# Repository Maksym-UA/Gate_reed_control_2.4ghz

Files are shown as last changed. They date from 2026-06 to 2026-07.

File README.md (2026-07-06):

# Gate Reed Control 2.4GHz & Telegram Bot

## Overview

Dual-board ESP32 project for gate door-state telemetry over ESP-NOW.

- Xiao ESP32-C3 acts as the transmitter
- ESP32-S3 acts as the receiver with Telegram bot push notifications
- Framework: ESP-IDF via PlatformIO
- Transport: ESP-NOW (2.4 GHz) + HTTPS (Telegram Bot API)

Each firmware keeps `src/main.cpp` minimal and places runtime logic in `src/application.cpp`.

## Demo

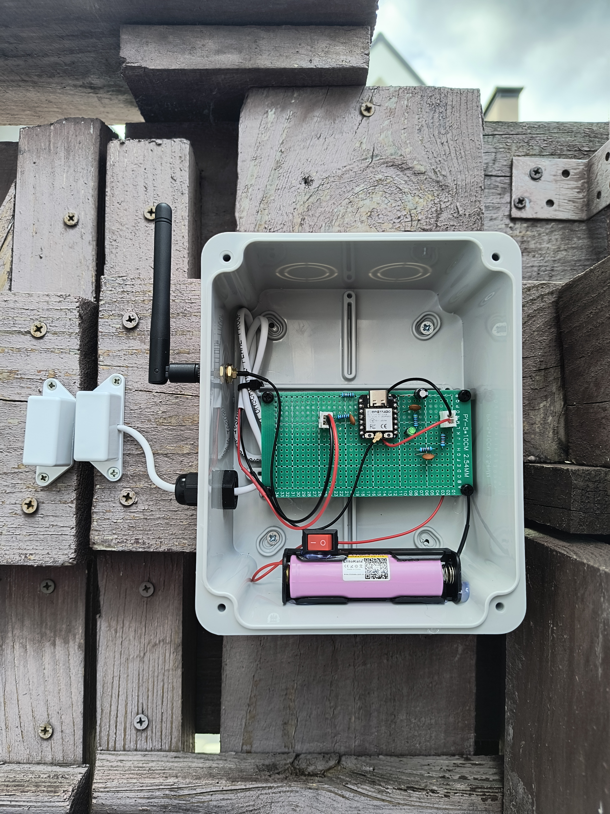
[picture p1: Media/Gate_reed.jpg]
Watch the demo (https://github.com/Maksym-UA/Gate_reed_control_2.4ghz/releases/download/v1.0.1/Reed_operation.mp4)


[Video walkthrough](https://github.com/Maksym-UA/Gate_reed_control_2.4ghz/releases/download/v1.0.1/Reed_operation.mp4)

_Fallback (repo file): [Media/Reed_operation.mp4](Media/Reed_operation.mp4)_

## Hardware

| Board | Role | Key GPIO |
|---|---|---|
| ESP32-C3 (Seeed XIAO ESP32C3) | Reed sensor reader + ESP-NOW TX + deep sleep | Reed: GPIO4, LED: GPIO20 |
| ESP32-S3 (ESP32-S3-DevKitC-1) | ESP-NOW RX + WiFi STA + Telegram bot | No sensor GPIO; WiFi used for Telegram HTTPS |

### Wiring Notes

- Use an external 100k pull-up resistor on ESP32-C3 GPIO4 for the reed input line for more efficient power management.
- Add an MTS-101 switch on the battery path so battery power can be disconnected while the ESP32-C3 is powered from USB.

## Communication Model

ESP32-C3 publishes gate state messages:

- `DOOR:OPEN`
- `DOOR:CLOSED`
- `BATT:X.XXV` (periodic battery voltage, e.g. `BATT:3.92V`)

ESP32-S3 listens on ESP-NOW, updates remote door state, and marks state as stale if no packet arrives for a timeout window.

## Build, Upload, Monitor

ESP32-C3:

```bash
cd ESP32-C3
pio run
pio run -t upload
pio device monitor -b 115200
```

ESP32-S3:

```bash
cd ESP32-S3
pio run
pio run -t upload
pio device monitor -b 115200
```

## Telegram Bot Setup

The ESP32-S3 connects to a Telegram bot to deliver door-state push notifications and respond to admin commands.

### Credentials

Credentials are stored in `ESP32-S3/lib/esp_now/telegram/secrets.h`, which is gitignored.

1. Copy the template:
   ```bash
   cp ESP32-S3/lib/esp_now/telegram/secrets.h.template \
      ESP32-S3/lib/esp_now/telegram/secrets.h
   ```
2. Fill in the values:
   ```c
   #define WIFI_SSID      "your_wifi_ssid"
   #define WIFI_PASSWORD  "your_wifi_password"
   #define TG_BOT_TOKEN   "123456:ABC-..."
   #define TG_CHAT_ID     "123456789"   // chat to receive notifications
   #define TG_ADMIN_ID    "123456789"   // user ID allowed to run admin commands
   ```
3. Create a bot with [@BotFather](https://t.me/BotFather) and copy the token.
4. Retrieve your chat/user ID via [@userinfobot](https://t.me/userinfobot) or `getUpdates`.

### Notifications

| Event | Telegram message |
|---|---|
| Door opened | 🚪 Двері ВІДЧИНЕНІ |
| Door closed | ✅ Двері ЗАЧИНЕНІ |
| Door still open (every 5 min) | ⚠️ Двері все ще ВІДЧИНЕНІ: Xхв Yс |

### Admin Commands

| Command / Button | Response |
|---|---|
| `/voltage` text message | Battery voltage or "no data yet" |
| `Check Voltage` inline button | Same as `/voltage` |

Only `TG_ADMIN_ID` receives voltage data; all others get an unauthorized reply.

### Transport

The bot uses **long-polling** (`getUpdates` with `timeout=25`). No webhook or public IP is required. All HTTPS calls run inside a dedicated `tg_task` FreeRTOS task so the main door-state loop never blocks on network I/O.

## Runtime Flow

ESP32-C3:

1. Initializes ESP-NOW, reed input, LED, and ADC voltage divider.
2. Reads current door state and transmits initial state (`BOOT` TX kind on first cold boot).
3. Blinks LED 3 times for OPEN, 1 time for CLOSED on state change.
4. On timer wake with unchanged state, transmits `KEEPALIVE` once the periodic keep-alive threshold is reached.
5. On timer wake, spawns a one-shot voltage task that reads the battery ADC and broadcasts `BATT:X.XXV` when the battery TX interval threshold is reached.
6. Waits in boot grace window (15 s) on cold boot to allow monitoring/flashing.
7. On wake from GPIO/timer, stays active briefly (3.5 s) to catch quick follow-up transitions.
8. Enters deep sleep; wakes on reed pin level change (GPIO wakeup) with a timer fallback wake.

ESP32-S3:

1. Initializes ESP-NOW, connects to WiFi, and starts the Telegram bot client.
2. Receives `DOOR:OPEN` / `DOOR:CLOSED` / `BATT:X.XXV` packets via ESP-NOW.
3. Tracks known/unknown remote door state; marks it stale after a timeout without packets.
4. Enqueues Telegram notifications: door opened, door closed, and a repeat reminder every 5 minutes while the door remains open.
5. Runs a dedicated `tg_task` (FreeRTOS) for all HTTPS operations — the main loop never blocks on network I/O.
6. Long-polls Telegram (25 s server timeout) for admin commands: `/voltage` text message and `CHECK_VOLTAGE` inline button.
7. Logs a periodic heartbeat with the current door state.

## System Architecture

This project follows a layered architecture across two boards:

- **ESP32-C3 transmitter** — reads the reed sensor, measures battery voltage, drives the status LED, and sends ESP-NOW packets.
- **ESP32-S3 receiver** — receives ESP-NOW packets, tracks remote state, and reports status through logs.

### GPIO Map

| Board | GPIO / Resource | Function |
|---|---|---|
| ESP32-C3 (Seeed XIAO ESP32C3) | GPIO4 | Reed sensor input |
| ESP32-C3 (Seeed XIAO ESP32C3) | GPIO2 | Battery voltage ADC input |
| ESP32-C3 (Seeed XIAO ESP32C3) | GPIO20 | Green LED output |
| ESP32-C3 (Seeed XIAO ESP32C3) | ESP-NOW / Wi-Fi | Wireless transmission |
| ESP32-C3 (Seeed XIAO ESP32C3) | Deep sleep wakeup | Wake by GPIO or timer |
| ESP32-S3 (ESP32-S3-DevKitC-1) | ESP-NOW / Wi-Fi | Wireless reception |
| ESP32-S3 (ESP32-S3-DevKitC-1) | UART | Debug and monitoring output |

### Peripheral List

ESP32-C3 transmitter:
- Reed switch sensor
- External 100k pull-up resistor on GPIO4
- RC input filter: 100Ω + 100nF
- Battery voltage divider on GPIO2: 220k / 220k
- ADC filter capacitor: 100nF
- Green LED with 470Ω resistor
- 18650 Li-ion battery
- Power switch
- ESP-NOW wireless interface

ESP32-S3 receiver:
- ESP-NOW wireless interface (2.4 GHz)
- WiFi STA (WPA2, used for Telegram HTTPS)
- UART logging interface

### Layer Model

#### Peripheral Layer
Handles low-level hardware setup.

ESP32-C3:
- Reed GPIO initialization
- LED GPIO initialization
- ADC initialization for battery sensing
- ESP-NOW initialization
- Deep sleep and wakeup source setup

ESP32-S3:
- ESP-NOW initialization
- UART/logger initialization

#### Logic Layer
Implements the application behavior.

ESP32-C3:
- Reed state reading
- Debounce/filtering
- Door state evaluation
- Keepalive scheduling
- Battery reporting scheduling
- Wake reason handling
- Sleep decision logic

ESP32-S3:
- Packet parsing
- Door state tracking
- Battery status update
- Timeout and stale-state detection

#### Transport / Output Layer
Handles communication and visible output.

ESP32-C3:
- ESP-NOW transmission of:
  - `DOOR:OPEN`
  - `DOOR:CLOSED`
  - `BATT:X.XXV`
- LED blink indication

ESP32-S3:
- ESP-NOW packet reception
- WiFi STA connection (WPA2)
- Telegram push notifications via HTTPS (`sendMessage`)
- Telegram long-poll command handler (`/voltage`, `CHECK_VOLTAGE` inline button)
- UART log output

#### Reliability Layer
Improves robustness and fault tolerance.

ESP32-C3:
- ADC averaging
- ADC settle delay before sampling
- ESP-NOW retry handling
- Wait for TX completion before sleep
- Deep sleep power saving
- GPIO/timer wakeup recovery

ESP32-S3:
- Timeout detection
- Stale-state handling
- Recovery after missed packets

### High-Level Architecture Diagram

```mermaid
flowchart LR
    subgraph TX["ESP32-C3 Transmitter"]
        RS["Reed Sensor"]
        BAT["18650 Battery"]
        SW["Power Switch"]
        LED["Green LED"]

        subgraph P1["Peripheral Layer"]
            GPIO["GPIO4 Reed Input"]
            ADC["GPIO2 ADC Battery Input"]
            LEDGPIO["GPIO20 LED Output"]
            ESPNOW1["ESP-NOW Init"]
            SLEEP1["Deep Sleep / Wakeup Init"]
        end

        subgraph L1["Logic Layer"]
            REEDLOGIC["Reed Read + Debounce"]
            FSM1["Door State FSM"]
            BATTLOGIC["Battery Read Scheduler"]
            KEEP["Keepalive Logic"]
        end

        subgraph O1["Transport / Output Layer"]
            TXMSG["ESP-NOW TX\nDOOR:OPEN / DOOR:CLOSED / BATT:X.XXV"]
            LEDPAT["LED Blink Patterns"]
        end

        subgraph R1["Reliability Layer"]
            AVG["ADC Averaging"]
            TXRETRY["TX Retry / Wait Complete"]
            WAKE["GPIO / Timer Wake Logic"]
        end

        RS --> GPIO
        BAT --> SW --> ADC
        BAT --> SW --> SLEEP1
        GPIO --> REEDLOGIC --> FSM1
        ADC --> BATTLOGIC
        FSM1 --> TXMSG
        KEEP --> TXMSG
        BATTLOGIC --> TXMSG
        FSM1 --> LEDPAT
        LEDPAT --> LEDGPIO --> LED

        ESPNOW1 --> TXMSG
        SLEEP1 --> WAKE
        AVG --> BATTLOGIC
        TXRETRY --> TXMSG
        WAKE --> FSM1
    end

    LINK["2.4 GHz ESP-NOW Link"]

    subgraph RX["ESP32-S3 Receiver"]
        subgraph P2["Peripheral Layer"]
            ESPNOW2["ESP-NOW Init"]
            WIFI["WiFi STA Init"]
            UART["UART / Serial Log Init"]
        end

        subgraph L2["Logic Layer"]
            PARSE["Packet Parser"]
            FSM2["Receiver State FSM"]
            STALE["Timeout / Stale Detection"]
            BATT2["Battery Status Update"]
            TG_QUEUE["Telegram Queue"]
            TG_TASK["tg_task\n(FreeRTOS)"]
        end

        subgraph O2["Transport / Output Layer"]
            LOG["UART Logs / Monitoring"]
            TG["Telegram Bot API\n(HTTPS long-poll + POST)"]
        end

        subgraph R2["Reliability Layer"]
            REC["Recovery / Timeout Handling"]
        end

        ESPNOW2 --> PARSE
        WIFI --> TG_TASK
        PARSE --> FSM2
        PARSE --> BATT2
        FSM2 --> TG_QUEUE
        BATT2 --> LOG
        TG_QUEUE --> TG_TASK
        TG_TASK --> TG
        FSM2 --> LOG
        STALE --> FSM2
        REC --> STALE
        UART --> LOG
    end

    TXMSG --> LINK --> ESPNOW2
```

### Transmitter Runtime FSM

```mermaid
stateDiagram-v2
    [*] --> BOOT
    BOOT --> INIT
    INIT --> CHECK_REED

    CHECK_REED --> SEND_EVENT : door changed
    CHECK_REED --> SEND_KEEPALIVE : keepalive due
    CHECK_REED --> READ_BATTERY : battery report due
    CHECK_REED --> PREPARE_SLEEP : no update needed

    SEND_EVENT --> BLINK_LED
    BLINK_LED --> WAIT_TX_DONE
    SEND_KEEPALIVE --> WAIT_TX_DONE
    READ_BATTERY --> SEND_BATTERY
    SEND_BATTERY --> WAIT_TX_DONE

    WAIT_TX_DONE --> PREPARE_SLEEP
    PREPARE_SLEEP --> DEEP_SLEEP
    DEEP_SLEEP --> WAKE

    WAKE --> CHECK_REED
```

### Receiver Runtime FSM

```mermaid
stateDiagram-v2
    [*] --> INIT
    INIT --> LISTENING

    LISTENING --> PARSE_PACKET : packet received
    PARSE_PACKET --> STATE_OPEN : DOOR:OPEN
    PARSE_PACKET --> STATE_CLOSED : DOOR:CLOSED
    PARSE_PACKET --> UPDATE_BATTERY : BATT:X.XXV

    STATE_OPEN --> ENQUEUE_NOTIFY : state changed
    STATE_OPEN --> LISTENING : keepalive (no change)
    STATE_CLOSED --> ENQUEUE_NOTIFY : state changed
    STATE_CLOSED --> LISTENING : keepalive (no change)
    ENQUEUE_NOTIFY --> LISTENING
    UPDATE_BATTERY --> LISTENING

    LISTENING --> ENQUEUE_REMIND : door open ≥ 5 min
    ENQUEUE_REMIND --> LISTENING

    LISTENING --> STATE_STALE : packet timeout
    STATE_STALE --> LISTENING : next valid packet
```

### Queue and Mutex Notes

- A **queue** is used when one task sends commands to another task.
- In this project, the LED control path is a queue-based interaction between application logic and the LED task.
- A **mutex** is needed when multiple tasks access the same shared resource.
- If multiple tasks transmit through the same ESP-NOW path, a mutex may be used to protect the shared transmission resource.

## Project Structure

```text
ESP32-C3/
  include/
    application.h
  lib/
    esp_now/
    led/
    reed/
    voltage/
  src/
    application.cpp
    main.cpp
  CMakeLists.txt
  platformio.ini

ESP32-S3/
  include/
    application.h
  lib/
    esp_now/
      esp_now.cpp
      espnow_service.h
      telegram/
        telegram.cpp
        telegram.h
        secrets.h          ← gitignored; copy from secrets.h.template
        secrets.h.template
  src/
    application.cpp
    main.cpp
  CMakeLists.txt
  platformio.ini

Gate_reed_control_2.4ghz.code-workspace
.gitignore
README.md
src/
```

## Notes

- ESP-NOW is connectionless and best-effort; RF environment affects reliability.
- Deep sleep on ESP32-C3 may make USB serial disappear until the next wake/reset.
- If VS Code shows stale Problems after successful builds, run a clean build and reload the window.
- `ESP32-S3/lib/esp_now/telegram/secrets.h` is gitignored. Copy `secrets.h.template` to `secrets.h` and fill in your credentials before building the S3 firmware.
- KiCAd Xiao ESP32-C3 footprint from https://github.com/VectorSpaceHQ/XIAO_ESP32C3
- Seeed Xiao ESP32-C3 Wiki https://wiki.seeedstudio.com/XIAO_ESP32C3_Getting_Started

## Contact

Feedback: max.savin3@gmail.com

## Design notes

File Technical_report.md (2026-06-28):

# Technical Report

## Abstract

This project implements a simple wireless gate monitoring system using two ESP32 boards and ESP-NOW communication. The ESP32-C3 transmitter reads a reed switch, measures battery voltage, and sends status packets. The ESP32-S3 receiver listens for these packets, updates the remote gate state, and reports the current status through logs.

The system was designed for low-power battery operation. The transmitter uses deep sleep, GPIO wakeup, timer wakeup fallback, and periodic battery reporting. The software is structured into four layers: Peripheral Layer, Logic Layer, Transport / Output Layer, and Reliability Layer. This makes the design easier to understand, test, and maintain.

Testing confirmed correct gate state detection, correct wireless transmission, and correct battery measurement after fixing the physical ADC wiring. The final result is a compact embedded system suitable for simple remote monitoring applications.

## Problem Statement

The goal of this project was to create a battery-powered embedded system that can detect whether a gate or door is open or closed and send this information wirelessly to another ESP32 board. The system also had to report battery voltage and support low-power operation.

The transmitter had to read a reed sensor, detect state changes, send updates through ESP-NOW, and spend most of its time in deep sleep to reduce power consumption. The receiver had to listen for incoming packets, track the last known state, and detect when communication becomes stale.

The solution had to remain simple, practical, and easy to test on real hardware.

## Review of Existing Solutions

A basic way to monitor a gate or door is to connect a reed switch directly to a wired alarm or controller input. This is reliable but requires cabling.

Wireless systems often use Wi-Fi, Bluetooth Low Energy, Zigbee, LoRa, or MQTT-based architectures. These solutions can be powerful, but they often require more infrastructure, more software complexity, or more power.

ESP-NOW is a lightweight wireless protocol supported by ESP32 devices. It does not require a router or access point and is well suited for simple ESP32-to-ESP32 communication. For this reason, it was selected as the communication method for this project.

Battery voltage measurement is commonly implemented with a resistor divider connected to an ADC pin. This project also uses that approach.

## Description of the Implemented System

The system consists of two nodes:

- **ESP32-C3 transmitter**
- **ESP32-S3 receiver**

### ESP32-C3 transmitter
The transmitter is powered by a single 18650 Li-ion battery. It reads the reed switch on GPIO4, measures battery voltage on GPIO2 through a resistor divider, and drives a green LED on GPIO20. It sends messages over ESP-NOW.

The transmitter sends:
- `DOOR:OPEN`
- `DOOR:CLOSED`
- `BATT:X.XXV`

To reduce power consumption, it enters deep sleep after completing active tasks. It wakes on reed state change or by timer.

### ESP32-S3 receiver
The receiver listens for ESP-NOW packets. It parses incoming messages, updates the current door state, stores the latest battery value, and detects stale communication if no packet arrives for a timeout period.

### Software structure
The software is divided into four layers:

- **Peripheral Layer** — GPIO, ADC, ESP-NOW, wakeup setup
- **Logic Layer** — reed processing, state decision, scheduling
- **Transport / Output Layer** — packet transmission, packet reception, LED indication, logging
- **Reliability Layer** — ADC averaging, retries, timeout handling, deep sleep recovery

This layered structure improves readability and maintenance.

## Results of Testing

The system was tested with real hardware.

### Reed sensor
The reed switch correctly changed the transmitted state between open and closed. The receiver correctly updated its monitored state.

### Battery measurement
At first, battery readings were incorrect because GPIO2 had been soldered to the wrong source. After the hardware fix, the measured battery voltage matched the expected value and the battery reporting worked correctly.

### Wireless communication
ESP-NOW packet transmission between the ESP32-C3 and ESP32-S3 worked correctly. The receiver successfully parsed door-state and battery messages.

### Power behavior
The transmitter successfully entered deep sleep and woke again on GPIO or timer events. This confirmed the low-power behavior required for battery operation.

## Conclusions

This project successfully implemented a simple wireless gate monitoring system using ESP32 boards and ESP-NOW.

The final system can:
- detect gate state using a reed switch,
- measure battery voltage,
- transmit telemetry wirelessly,
- receive and monitor remote state,
- operate in low-power sleep mode.

An important lesson from the project was that hardware validation is as important as firmware development. The ADC issue was caused by incorrect physical wiring, not by software logic. After fixing the hardware, the system worked as intended.

The project provides a solid foundation for future improvements such as stronger power optimization, additional status reporting, or integration with a larger monitoring system.

## Credits

### Frameworks and libraries
- **ESP-IDF** — Espressif IoT Development Framework
  License: Apache License 2.0
- **PlatformIO** — build and upload environment

### Documentation
- **Espressif Documentation**
  - ESP-NOW API
  - ADC configuration and calibration
  - GPIO configuration
  - Deep sleep and wakeup modes
- **Seeed Studio XIAO ESP32C3 documentation**
- **ESP32-S3-DevKitC-1 documentation**

### Hardware / PCB references
- **XIAO ESP32-C3 KiCad footprint/library**
  Source: VectorSpaceHQ GitHub repository
  License: verify repository license before final submission

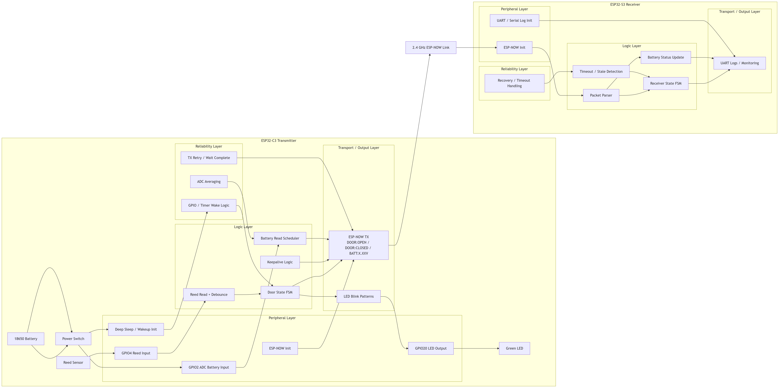
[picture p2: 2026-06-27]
Diagrams/architecture-diagram-2026-06-27-030606.png

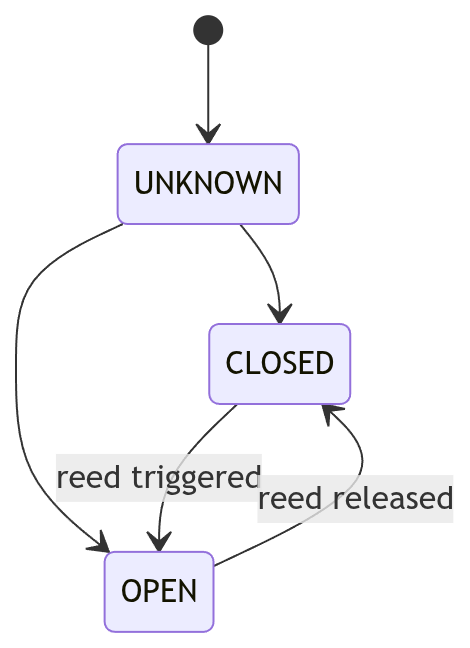
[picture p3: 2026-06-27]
Diagrams/door-state-diagram-2026-06-27-030727.png

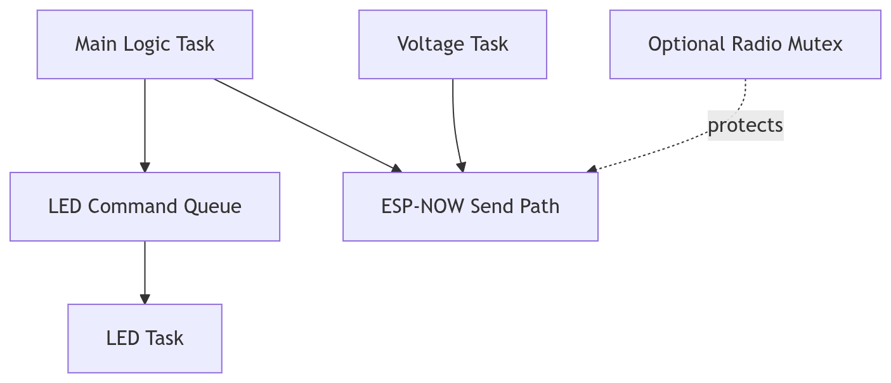
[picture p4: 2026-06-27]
Diagrams/queue-mutex-diagram-2026-06-27-030647.png

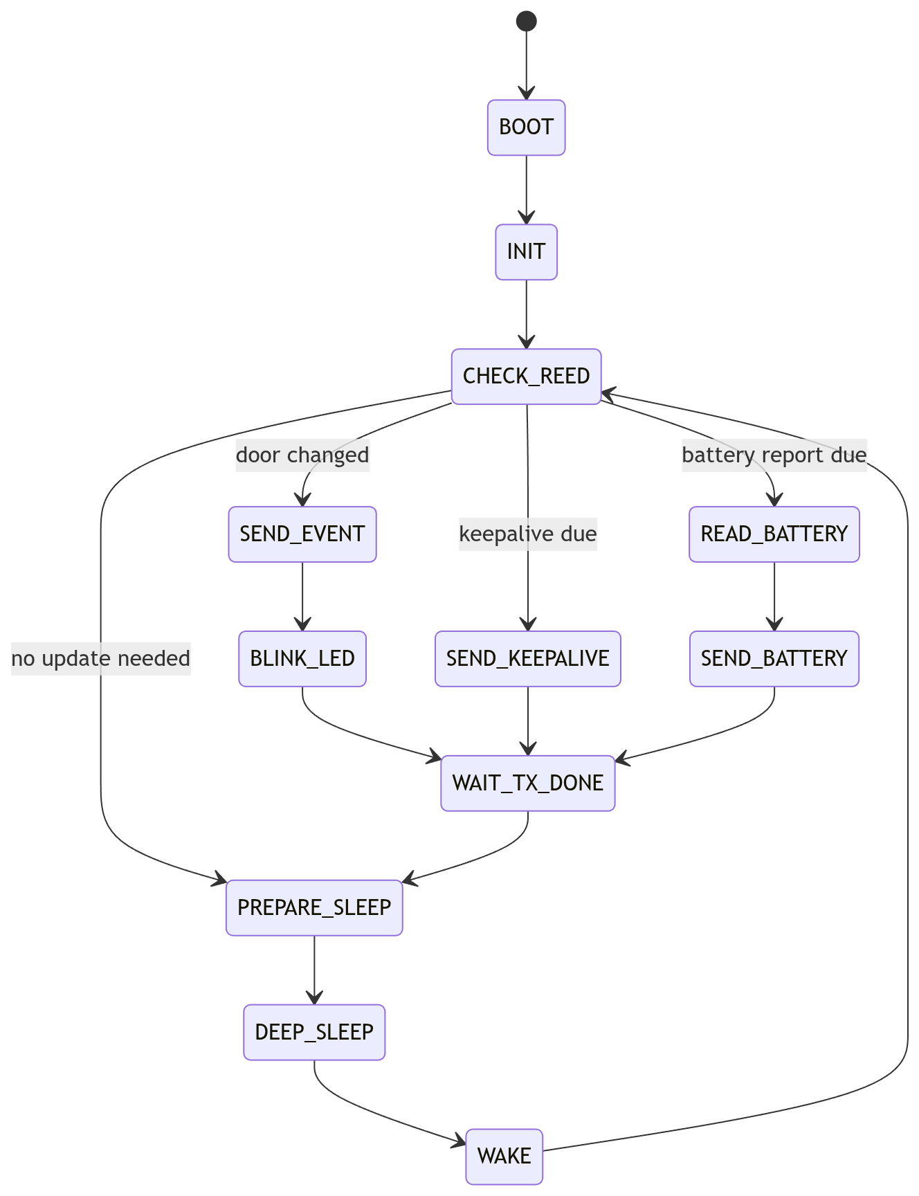
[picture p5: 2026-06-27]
Diagrams/transmitter-fsm-diagram-2026-06-27-030314.png

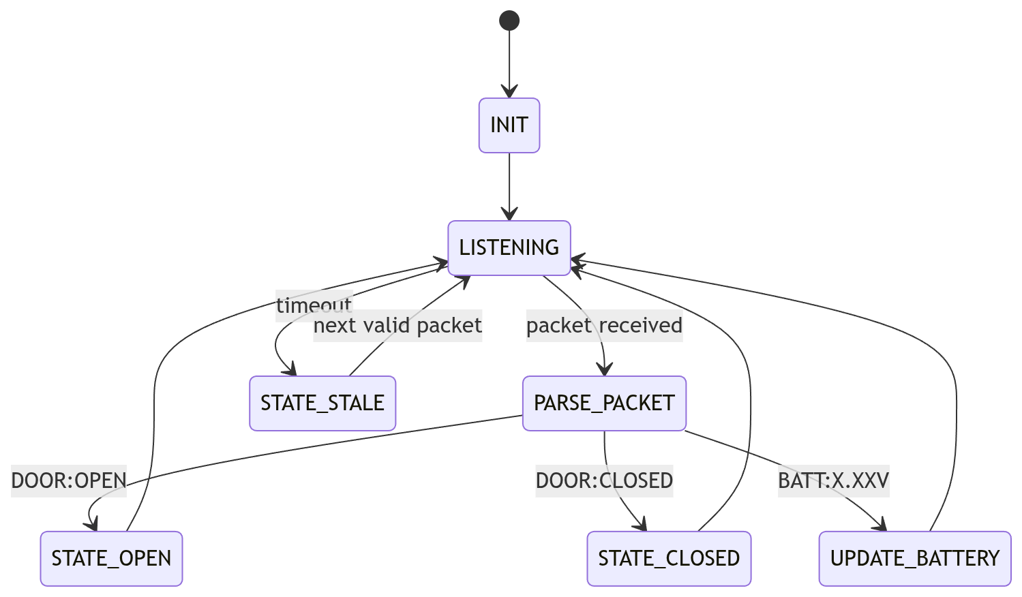
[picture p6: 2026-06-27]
Diagrams/receiver-fsm-diagram-2026-06-27-030450.png

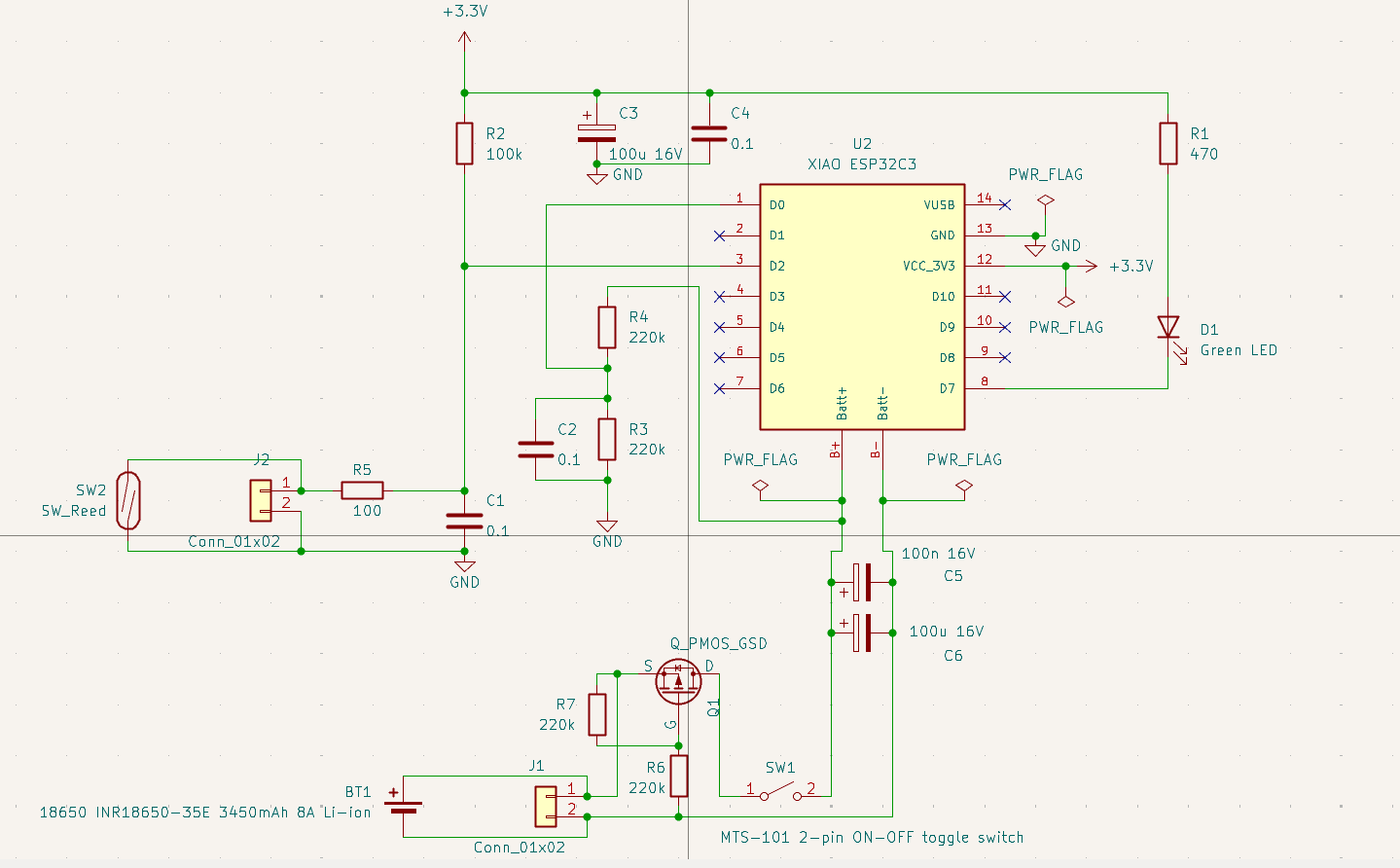
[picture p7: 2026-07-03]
Diagrams/Kicad.png

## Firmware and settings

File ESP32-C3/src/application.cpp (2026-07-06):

#include "application.h"

#include <string.h>

#include "driver/gpio.h"
#include "esp_attr.h"
#include "esp_log.h"
#include "esp_sleep.h"
#include "esp_timer.h"
#include "espnow_service.h"
#include "freertos/FreeRTOS.h"
#include "freertos/event_groups.h"
#include "freertos/task.h"
#include "led.h"
#include "reed.h"
#include "voltage.h"

namespace app {

  static const char *TAG = "gate_reed";
  static const int kBootUsbGraceMs = 15000;
  static const int64_t kFallbackWakeupIntervalMs = 3000;
  static const int64_t kOpenStateWakeupIntervalMs = 30000;
  static const int64_t kKeepAliveWakeupIntervalMs = 60000;  // 1 min when closed — GPIO wakeup is the primary trigger; timer is fallback
  static const int64_t kPeriodicKeepAliveMs = 30000;               // keepalive fires every timer wake in both states
  static const int kPostWakeActiveMs = 3500;


  static const char *wakeup_cause_to_string(esp_sleep_wakeup_cause_t cause) {
    switch (cause) {
      case ESP_SLEEP_WAKEUP_UNDEFINED:
        return "UNDEFINED";
      case ESP_SLEEP_WAKEUP_EXT0:
        return "EXT0";
      case ESP_SLEEP_WAKEUP_EXT1:
        return "EXT1";
      case ESP_SLEEP_WAKEUP_TIMER:
        return "TIMER";
      case ESP_SLEEP_WAKEUP_TOUCHPAD:
        return "TOUCHPAD";
      case ESP_SLEEP_WAKEUP_ULP:
        return "ULP";
      case ESP_SLEEP_WAKEUP_GPIO:
        return "GPIO";
      case ESP_SLEEP_WAKEUP_UART:
        return "UART";
      default:
        return "OTHER";
    }
  }

  static Config s_config = {};
  static bool s_initialized = false;
  static esp_sleep_wakeup_cause_t s_wakeCause = ESP_SLEEP_WAKEUP_UNDEFINED;
  RTC_DATA_ATTR static bool s_lastPublishedDoorOpen = false; // RTC_DATA_ATTR retains value across deep sleep cycles
  RTC_DATA_ATTR static bool s_lastPublishedDoorOpenValid = false;
  RTC_DATA_ATTR static uint32_t s_unchangedTimerWakeCount = 0;

  // LED blink command posted to s_ledQueue by the main task.
  struct LedCmd {
    int count;
    int on_ms;
    int off_ms;
  };

  // FreeRTOS objects for LED blink and voltage TX tasks.
  // The main task waits for both to finish before entering deep sleep.
  static QueueHandle_t      s_ledQueue      = nullptr;
  static EventGroupHandle_t s_ledEvents     = nullptr;
  static TaskHandle_t       s_ledTaskHandle = nullptr;
  static const EventBits_t  kLedIdleBit     = BIT0;
  static const EventBits_t  kVoltIdleBit    = BIT1;
  static const EventBits_t  kAllIdleBits    = BIT0 | BIT1;

  static void blink_state_feedback(bool open);
  static void led_task(void *arg);
  static void voltage_task(void *arg);

  static void print_door_state(bool open) {
    if (open) {
      ESP_LOGI(TAG, "DOOR: OPEN");
    } else {
      ESP_LOGI(TAG, "DOOR: CLOSED");
    }
  }

  // Posts a blink command to the LED task queue (non-blocking).
  // The LED task executes the sequence at priority 3 so the main sensor
  // loop (priority 5) keeps polling the reed switch during blink delays.
  static void blink_state_feedback(bool open) {
    if (s_ledQueue == nullptr) return;
    const LedCmd cmd = open ? LedCmd{3, 80, 80} : LedCmd{1, 250, 0};
    xQueueSend(s_ledQueue, &cmd, pdMS_TO_TICKS(200));
  }

  // Low-priority LED task: drives GPIO based on commands from s_ledQueue.
  // Signals idle via kLedIdleBit so enter_deep_sleep_for_next_change() can
  // wait for any in-progress blink to finish before sleeping.
  static void led_task(void *) {
    while (true) {
      LedCmd cmd;
      xQueueReceive(s_ledQueue, &cmd, portMAX_DELAY);
      xEventGroupClearBits(s_ledEvents, kLedIdleBit);  // busy
      for (int i = 0; i < cmd.count; ++i) {
        led::set_led(true);
        vTaskDelay(pdMS_TO_TICKS(cmd.on_ms));
        led::set_led(false);
        if (cmd.off_ms > 0) vTaskDelay(pdMS_TO_TICKS(cmd.off_ms));
      }
      led::set_led(false);
      vTaskDelay(pdMS_TO_TICKS(50));
      xEventGroupSetBits(s_ledEvents, kLedIdleBit);    // idle
    }
  }

  // One-shot battery voltage task: reads ADC, broadcasts BATT message, then waits
  // for ESP-NOW TX to complete (send_broadcast is async) before signalling idle
  // and self-deleting. Runs at priority 2.
  static void voltage_task(void *) {
    // Allow the RC voltage-divider node to settle after wake before sampling.
    vTaskDelay(pdMS_TO_TICKS(20));
    const float v = voltage::read_voltage();
    char msg[16];
    snprintf(msg, sizeof(msg), "BATT:%.2fV", v);
    ESP_LOGI(TAG, "Battery voltage: %.2fV", v);
    espnow::send_broadcast(reinterpret_cast<const uint8_t *>(msg), strlen(msg));
    // esp_now_send() is async; wait for the WiFi driver to complete the TX
    // before signalling idle, otherwise deep sleep kills the packet in flight.
    vTaskDelay(pdMS_TO_TICKS(200));
    if (s_ledEvents != nullptr) {
      xEventGroupSetBits(s_ledEvents, kVoltIdleBit);
    }
    vTaskDelete(nullptr);
  }

  static bool publish_door_state(bool open, const char *txKind) {
    const char *message = open ? "DOOR:OPEN" : "DOOR:CLOSED";
    ESP_LOGI(TAG, "ESP-NOW TX [%s]: %s", txKind, message);

    for (int attempt = 0; attempt < 3; ++attempt) {
      esp_err_t sendRet = espnow::send_broadcast(
          reinterpret_cast<const uint8_t *>(message),
          strlen(message));
      if (sendRet == ESP_OK) {
        s_lastPublishedDoorOpen = open;
        s_lastPublishedDoorOpenValid = true;
        return true;
      }

      ESP_LOGW(TAG, "ESP-NOW send failed (attempt %d): %s",
              attempt + 1, esp_err_to_name(sendRet));
      vTaskDelay(pdMS_TO_TICKS(40));
    }

    ESP_LOGW(TAG, "ESP-NOW TX [%s] dropped after retries: %s", txKind, message);
    return false;
  }
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

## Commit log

2026-06-16 Cleaned up ESP32-C3
2026-06-16 Add ESP32-S3 alongside ESP32-C3 in monorepo
2026-06-16 Add root gitignore for ESP32-C3 and ESP32-S3
2026-06-16 Remove legacy root-level files; ESP32-C3 and ESP32-S3 are now top-level project folders
2026-06-17 Added sleep mode to ESP32-C3
2026-06-17 Added a sleep mode to ESP32-C3
2026-06-17 Updated the deep sleep logic for ESP32-C3
2026-06-18 updated readme and disaled pullup in sensor config
2026-06-22 Updated sleep/wake logic when working on battery
2026-06-23 Added queues and voltage log and voltage sampling
2026-06-27 Added Mermaid diagnrams and Kicad shemes
    [Gate reed.kicad_pcb, Gate reed.kicad_sch]
2026-07-03 Added comments to the code and added mosfet to kicad scheme
    [Gate reed.kicad_sch]
